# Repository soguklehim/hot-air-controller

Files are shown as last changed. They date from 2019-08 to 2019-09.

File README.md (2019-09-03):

# Hot Air Rework Controller for generic 858D / 85x heat guns

A small, portable and robust hot air controller for generic Chinese 858D / 8586 / 8858 / 852 / 878 / 858 hot air guns.

### Index
- [Schematics and BOM](/hardware)
- [Docs (guide for selecting and testing compatible hot air guns, assembly documents, manual)](/docs)
- Software (coming soon)

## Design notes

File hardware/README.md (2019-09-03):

### Table of contents

This project consists of two boards: Control and Power.

- Schematics: click on PDF files above
- BOM: click on XLSX files above
- Cutting files for SMD stencil: click on DXF files above

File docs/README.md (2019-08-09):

### Table of contents

- [User's manual](manual.md)
- [Guide for selecting and testing compatible hot air guns](hotairgun_guide.md)
- [PCB and assembly notes](pcb_assembly_notes.md)
- [A copy of the product description on Tindie, for version control](product_description.md)

You can get the boards or the complete controller on my store.



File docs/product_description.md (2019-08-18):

Hot Air Rework Controller for generic 858D / 85x heat guns

A small, portable and robust hot air controller for generic Chinese 858D / 8586 / 8858 / 852 / 878 / 858 hot air guns.

> Please note: Since Tindie does not allow shipping tiers based on product option, I need to select an option that can cover shipping of the assembled controller. Shipping blank boards cost less so I reduced its price to compensate that. I had to write this based on feedback received. Hope that's clear. Thank you.

## General Specifications and Features

-   Designed to use with Chinese 858D / 8586 / 8858 / 852 / 878 / 858 hot air guns.
-   Aims to be a safer alternative compared to existing controllers. For example:
    -   It will [not](https://www.youtube.com/watch?v=WPy9XYGDmWQ) [try](https://www.youtube.com/watch?v=WPy9XYGDmWQ) [to](https://www.youtube.com/watch?v=A319o8Ji4oI) [kill](https://www.youtube.com/watch?v=pgR7YbXUivs) [you](https://www.eevblog.com/forum/chat/deadly-wiring-fault-atten-858d-hot-air-rework-station/) (if you have a GFCI): Mains and earth connection are correctly wired.
    -   It will not [spontaneously combust](https://www.youtube.com/watch?v=tUFW5teeRBM) when left alone: Cuts off the hot air gun heater completely from mains after an idle timeout. Protects even if the unlikely event of TRIAC failure thanks to an internal relay.
    -   Safe to remove/change hot air gun while powered on: Both mains hot and neutral is disconnected from the front connector when the tool is removed so it is always safe to touch. 
-   Celsius or Fahrenheit display modes.
-   Works with the stand/holder: You can use the original holder or make your own with magnets.
-   Cools the tool down when in stand, with set thresholds.
-   Goes to sleep if left on stand. Selectable intervals or can be disabled. Wakes up automatically when needed.
-   Selectable power-on temperature and air: It can remember the last used settings as well (default).
-   Power limit: You can limit the maximum heating power on demand. Useful with under-powered UPSes or generators.
-   Selectable AC power regulation strategy: Phase angle (more precise) or pulse skip (less noisy).\* 
-   Internal temperature sensor used for compensating ambient temperature.
-   Manual calibration for ambient and tool set temperature.
-   Controller itself will work with 100-250V AC, 30-80Hz. (but you MUST use a hot air gun that rated for your mains voltage)

## Video
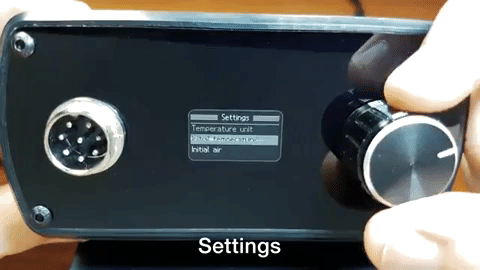
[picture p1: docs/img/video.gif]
Hot Air Rework Controller (https://youtu.be/jJAIh5CGPLk)


## Important!

This product is only a controller for specified hot air guns. **You must also have the hot air gun itself and its stand for a working system. These are not included.** These hot air guns are cheap and may arrive defective from manufacturing or shipping. Defective/incompatible hot air guns may damage the controller and/or trip your GFCI or worse. **It is entirely your responsibility to check if the hot air gun is compatible and not defective (use my guide for this). I cannot be held responsible if anything bad happens to controller or you. This is a DIY product. It does not have any certifications. I hope you have been sufficiently warned.**

[Click here for the hot air gun guide](https://github.com/soguklehim/hot-air-controller/blob/master/docs/hotairgun_guide.md)

## Options

You have three options that you can choose based on how adventurous are you.

1.  **Fully assembled controller**
    
    -   Includes one Hot Air Controller, tested and ready to work.
	
2.  **Assembled boards**
    
    -   Includes one front panel assembly (Control board + front panel) and one Power board, with all components mounted and tested.
    -   This is equals to Option 1 minus the case, back panel and AC socket. Mount it to a case of your liking, wire Power board to AC mains connection and it is ready to work.
	
3.  **Empty boards**
    
    -   Includes one blank Control board and one blank Power board. Without components, **but an unsoldered, preprogrammed ATMEGA328P-AU will be included** for the controller board. Use the provided BOM and your DIY skills for a working controller.

## You'll also need (not included)

-   AC power cable 
-   Hot air gun
-   Hot air gun stand

## Open(-ish) source

**Following elements of this product are available free of charge:**

-   Control and power board schematics
-   Control and power board BOM and assembly guide
-   Open source version of source code (coming soon)
    -   If you purchase an option that includes an assembled control board, it'll sent preprogrammed with the "closed" version of the code. Open source version has different fonts and temperature control algorithm (because I can't redistribute the sources of these). Otherwise, functionality is the same. 

> Originally this is going to be closed source (like all of my hardware products) but I decided to release an open version of the work due to popular demand. Porting things to Arduino ecosystem and replacing/rewriting/converting closed source to open takes time. It is still ongoing and I'm currently investing my time on that but it is not my first priority. Thank you for your understanding.

All assembled control boards ships with unlocked Optiboot bootloader. ICSP pins are also broken out if you really need that 0.5K. Happy hacking!

[Link to the repo](https://github.com/soguklehim/hot-air-controller/)

## Physical:

-  Dimensions: 110x105x50mm
-  Weight: 400gr

## Notes:

-   Currently shipping:
	-   Firmware: v1.0.24
    -   Control board: v1.0
    -   Power board: v1.1
-   AC input socket: IEC 60320 C14: Also known as "computer cable". (for assembled option)
-   Please read the "Shipping Policies" section at the store page ("View Store" button) before ordering.

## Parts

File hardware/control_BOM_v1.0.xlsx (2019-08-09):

Parts | Qty | Value | Description
C1, C2, C8, C9 | 4 | 10n | Multilayer Ceramic Capacitors MLCC - SMD/SMT 10nF 100V 0805 RoHS
C11 | 1 | 1u | Multilayer Ceramic Capacitors MLCC - SMD/SMT 1uF 50V 0805 RoHS
C13 | 1 | 220u 10V | Aluminum Electrolytic Capacitors - SMD 220uF ±20% 16V SMD,6.3x7.7mm RoHS
C3, C6, C10, C12, C14 | 5 | 100n | Multilayer Ceramic Capacitors MLCC - SMD/SMT 100nF 50V 0805 RoHS
C4, C5 | 2 | 22p | Multilayer Ceramic Capacitors MLCC - SMD/SMT 22pF 50V 0805 RoHS
C7 | 1 | 100u 35V | Aluminum Electrolytic Capacitors - SMD 100uF ±20% 35V SMD,6.3x7.7mm RoHS
D1 | 1 | SM4007PL | Diodes - General Purpose 1kV 1A 1.1V @ 1A SOD-123FL RoHS
D2 | 1 | BAV199 | Diodes - General Purpose 85V 160mA 1.25V @ 150mA SOT-23(SOT-23-3) RoHS
F1 | 1 | PTC 750mA | PTC Resettable Fuses 1206 RoHS
IC1 | 1 | GS8591 | Precision OpAmps SOT-23-5 RoHS
IC3 | 1 | 78M05 | Linear Voltage Regulators TO-252-2(DPAK) RoHS
LED1 | 1 | Green | Light Emitting Diodes (LED) Green 525~530nm 500~1080mcd@20mA Top View 1206 RoHS
NTC | 1 | 10k | NTC Thermistors 10KOhms ±5% 3950K 0805 RoHS
Q1 | 1 | AO3406 / CJ2306 | MOSFET N Trench 30V 3.16A 3V @ 250uA 47 mΩ @ 3.5A,10V SOT-23(SOT-23-3) RoHS
R1, R2, R8, R9, R11, R16, R17 | 7 | 10k | Chip Resistor - Surface Mount 10KOhms ±1% 1/8W 0805 RoHS
R12, R13 | 2 | 4k7 | Chip Resistor - Surface Mount 4.7KOhms ±1% 1/8W 0805 RoHS
R15 | 1 | 3k | Chip Resistor - Surface Mount 3KOhms ±1% 1/8W 0805 RoHS
R18 | 1 | 330 | Chip Resistor - Surface Mount 330Ohms ±1% 1/8W 0805 RoHS
R19 | 1 | 15k | Chip Resistor - Surface Mount 15KOhms ±1% 1/8W 0805 RoHS
R3 | 1 | 1M | Chip Resistor - Surface Mount 1MOhms ±1% 1/8W 0805 RoHS
R4 | 1 | 100k | Chip Resistor - Surface Mount 100KOhms ±1% 1/8W 0805 RoHS
R5, R14, R20 | 3 | 470k | Chip Resistor - Surface Mount 470KOhms ±1% 1/8W 0805 RoHS
R6 | 1 | 150 | Chip Resistor - Surface Mount 150Ohms ±1% 1/8W 0805 RoHS
R7, R10 | 2 | 1k | Chip Resistor - Surface Mount 1KOhms ±1% 1/8W 0805 RoHS
U1 | 1 | ATMEGA328P-AU | ATMEL & AVR TQFP-32_7x7x08P RoHS
X2 | 1 | JST-XH-05 | Wire To Board / Wire To Wire Connector Plugin RoHS
Y1 | 1 | 16MHz | SMD Crystal Resonators 16MHz ±20ppm HC-49SMD RoHS
-no designator- | 1 | 33uF 35V | to be soldered on hot air connector pins 5 and 6

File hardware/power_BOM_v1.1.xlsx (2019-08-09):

Parts | Qty | Value | Description
CX1 | 1 | 10n | Suppression Capacitors 10nF ±10% Through Hole,P=10mm RoHS
D1 | 1 | SM4007PL | Diodes - General Purpose 1kV 1A 1.1V @ 1A SOD-123FL RoHS
D2 | 1 | P6KE440CA | TVS DO-15 RoHS
HS1 | 1 | HEATSINK | Heat Sinks 32*7*22 RoHS
K1 | 1 | HCP2-DC24V-C | Relays General Purpose Non Latching 24VDC DPDT 8A (440VAC , 120VDC) Max Plugin RoHS
M1 | 1 | GMY-001F | https://www.aliexpress.com/item/AC-100-265V-to-DC-24V-1A-Switching-Power-Supply-Module-Board-For-Replace-Repair/32862962719.html
OK1 | 1 | PC814 | DIP Optocouplers SMD-4 RoHS
OK2 | 1 | MOC3053S | Triac Optocouplers SMD-6 RoHS
Q1 | 1 | AO3406 | MOSFET N Trench 30V 3.16A 3V @ 250uA 47 mΩ @ 3.5A,10V SOT-23(SOT-23-3) RoHS
R1, R2, R3, R4 | 4 | 39k | Chip Resistor - Surface Mount 39KOhms ±5% 1/2W 2010 RoHS
R10 | 1 | 39 | Metal Film Resistor (TH) 39Ohms ±1% 1W Axial RoHS
R11 | 1 | 10D431K | Varistors 350V 430(387~473) 710V 2.5KA Through Hole RoHS
R5 | 1 | 1k | Chip Resistor - Surface Mount 1KOhms ±1% 1/8W 0805 RoHS
R6 | 1 | 10k | Chip Resistor - Surface Mount 10KOhms ±1% 1/8W 0805 RoHS
R7 | 1 | 330 | Chip Resistor - Surface Mount 330Ohms ±1% 1/8W 0805 RoHS
R8 | 1 | 360 | Chip Resistor - Surface Mount 360Ohms ±5% 3/4W 2010 RoHS
R9 | 1 | 330 | Chip Resistor - Surface Mount 330Ohms ±5% 3/4W 2010 RoHS
T1 | 1 | BTA16 | Thyristors - TRIACs Two-way thyristor 600V TO-220(TO-220-3) RoHS
X1 | 1 | JST-XH-02-PIN | Wire To Board / Wire To Wire Connector Plugin RoHS
X2 | 1 | JST-XH-03-PIN | Wire To Board / Wire To Wire Connector DIP RoHS
X3 | 1 | 7.62mm Screw Terminal | Barrier Terminal Blocks 7.62mm RoHS OR Blade Terminals
X4 | 1 | JST-XH-05-PIN | Wire To Board / Wire To Wire Connector Plugin RoHS
X5 | 1 | B3P-VH | Wire To Board / Wire To Wire Connector P=3.96mm RoHS
- | 4 | PCB nylon standoff | 3mm hole size 5mm height self retaining spacers

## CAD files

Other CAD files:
hardware/power-bcream.dxf
hardware/control-bcream.dxf

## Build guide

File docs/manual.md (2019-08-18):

# User's Manual
##### For v1.0.24 SW

## Table of contents
- [Getting started](#getting-started)
- [How to use](#how-to-use)
- [Settings menu](#settings-menu)
- [Troubleshooting](#troubleshooting)
- [Calibration](#calibration)

---

## Getting started
This document assumes that you have:
- An assembled Controller from us OR made your DIY version and fully tested beforehand,
- Followed the [hot air gun guide](hotairgun_guide.md) and have a suitable hot air gun and a stand at hand,
- Installed the correct fuse for your country (220V: 4A, 110V: 8A) to the Controller,
- Connected the Controller to a GFCI protected outlet.

The Controller itself can work with 100-250V AC, 30-80Hz and requires a clean AC line, like all TRIAC based devices. **Using it with generators or especially modified sine / square wave / line-interactive / cheap UPSes is not recommended.** True sine wave / online UPSes over 1KVa should work fine. In fact, the Controller designed to tolerate dirty networks and more forgiving than most appliances but reliable operation is not guaranteed if anything other than your standard AC line is being used.

---

## How to use
You control everything with the knob. Rotating right (clockwise) means increase; rotating left (counterclockwise) is decrease. Short press (click) will change between temperature and air in the main screen, it means select/OK on settings. A long press will take you to the settings, or takes you back to the main screen if you're already in a menu.

This is the main screen.

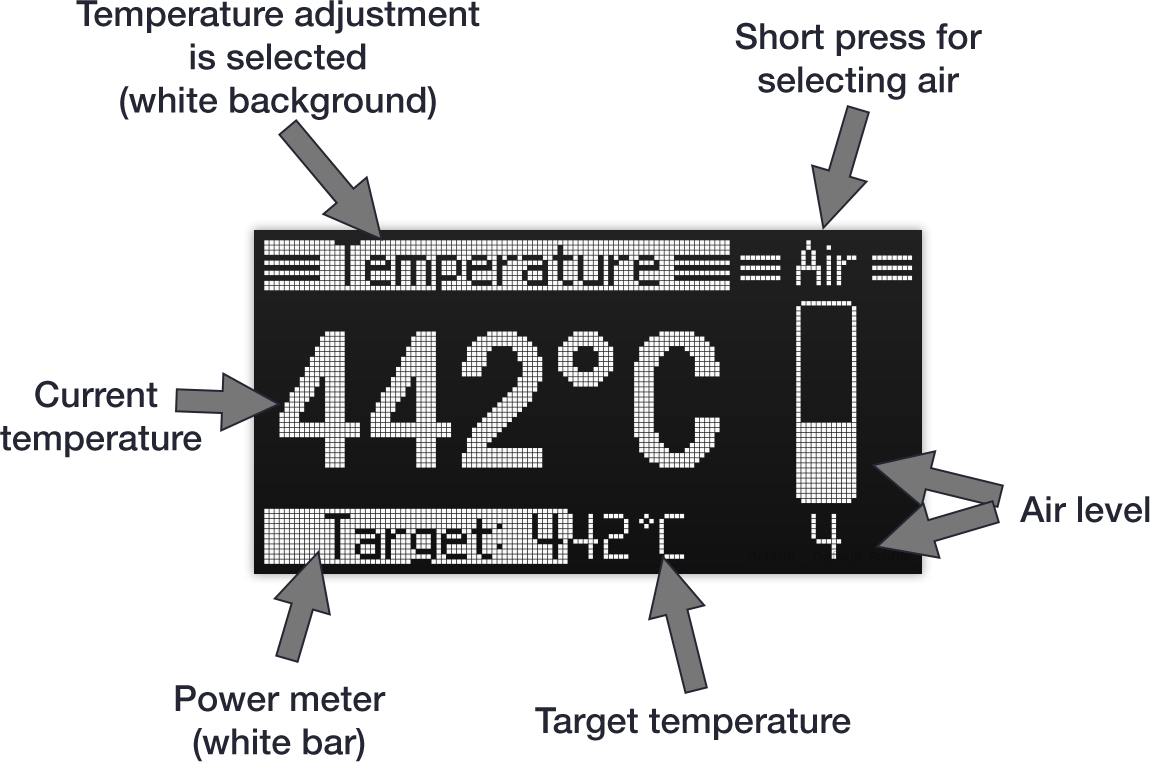
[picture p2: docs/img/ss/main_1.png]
main_1


You can choose to adjust temperature and air. Currently temperature is selected, so if you rotate the knob the set (target) temperature will change. 

While you're changing the temperature, the set value moves to the top for a short period so you can see and adjust it easier. In that short period, the current temperature can be seen at bottom.

For changing the selection, "click" (shortly press) the knob.

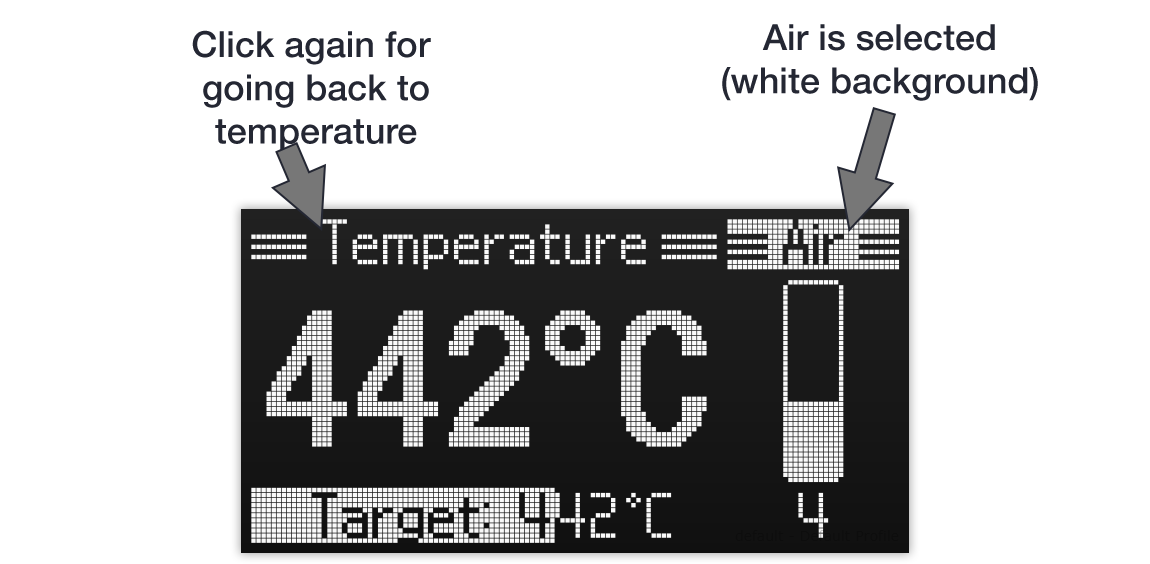
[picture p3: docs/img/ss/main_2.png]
main_2


Now the air is selected. You can change the air setting by rotating the knob.

If you put the tool on stand, Controller switches to Standby mode. It'll start to cool the nozzle using with maximum air speed. Fan will stop when it is cooled down. When you pick it from the stand, it immediately starts heating using the last temperature and air values.

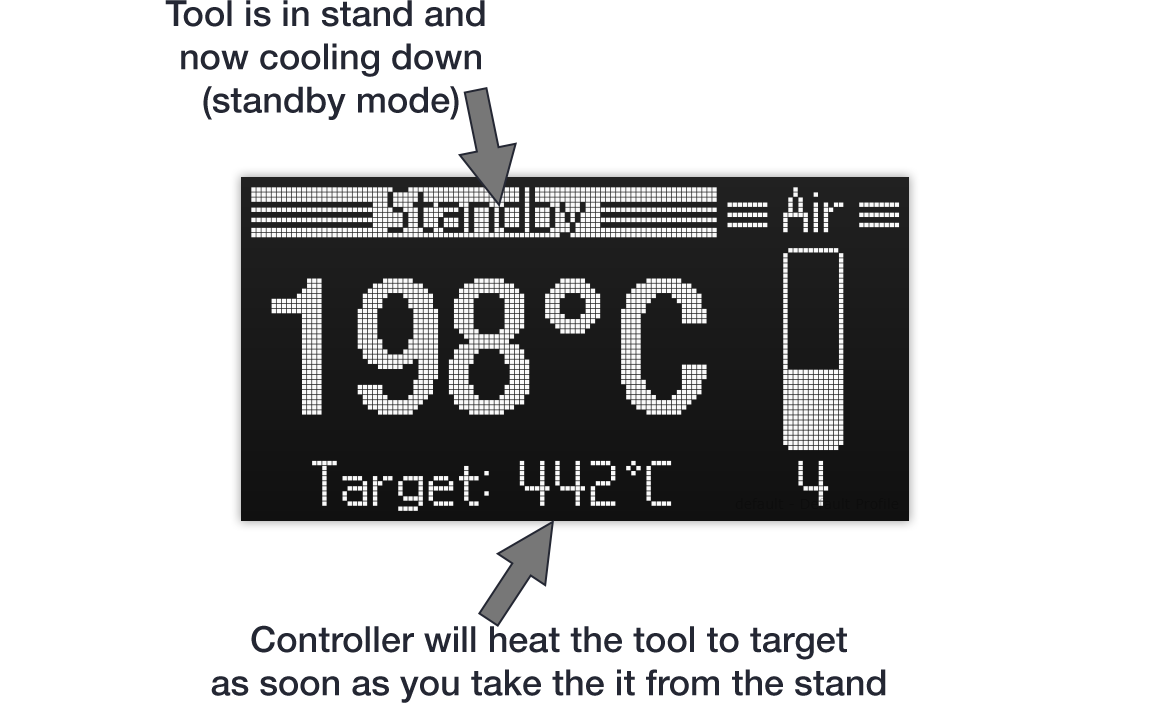
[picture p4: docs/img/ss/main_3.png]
main_3


That's it. Happy reworking!

---

## Settings menu

A long press to the knob will take you to the settings. It takes you back to the main screen if you're already in a menu. Use the long press for exit without saving. Click (short press) for choosing the selected option.

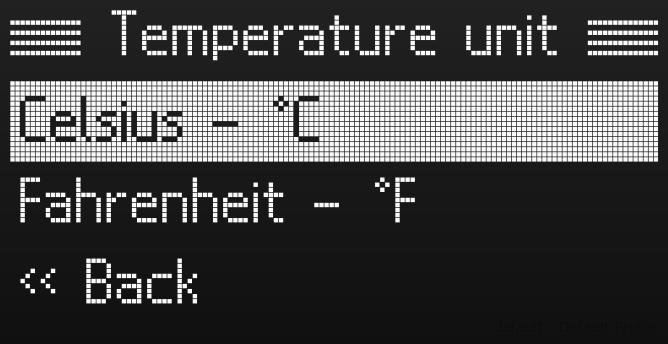
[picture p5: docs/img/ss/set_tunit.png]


**Temperature unit** 

You can select your temperature unit of your choice between Celsius or Fahrenheit.
<br clear="both"/>

------

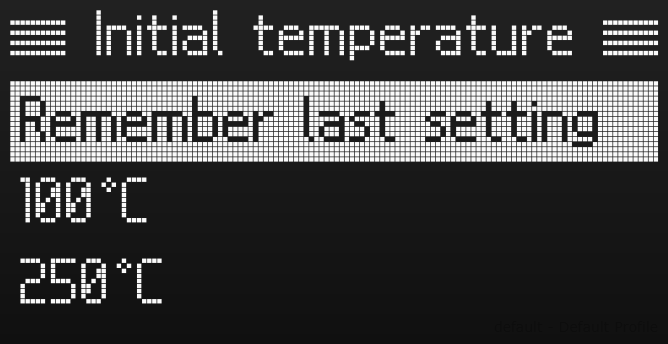
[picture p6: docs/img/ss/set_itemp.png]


**Initial temperature** 

You can select the temperature when the Controller boots up. It'll remember the last setting by default.
<br clear="both"/>

------

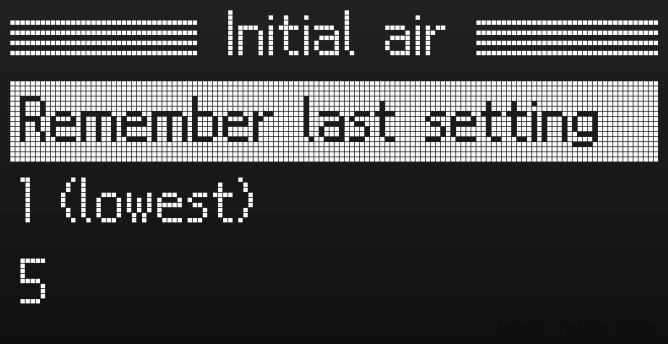
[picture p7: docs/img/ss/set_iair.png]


**Initial air**

You can select the air when the Controller boots up. It'll remember the last setting by default.
<br clear="both"/>

------

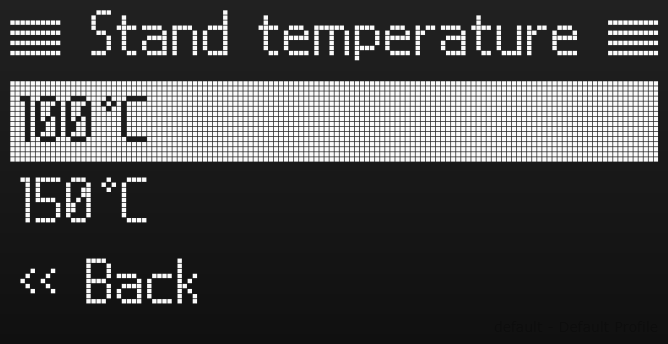
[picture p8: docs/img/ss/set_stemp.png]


**Stand temperature** 

Controller will cool the tool when it is in the stand for safety purposes. You can set that cooldown threshold here.
<br clear="both"/>

------

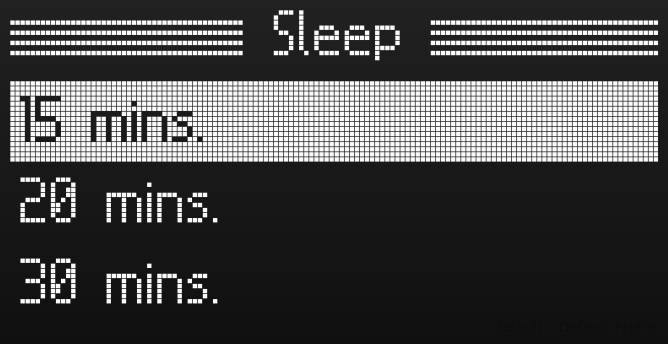
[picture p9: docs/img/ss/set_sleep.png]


**Sleep** 

Controller will enter to sleep mode if the tool stays in the stand for a while. You can select that timeout here. It will wake up when you take the tool from the stand, remove the tool or touch the encoder. 
<br clear="both"/>

------

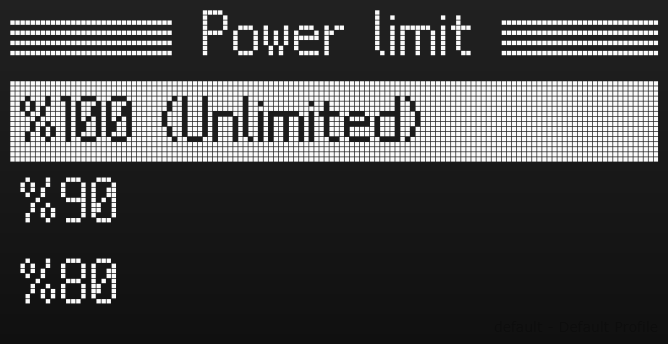
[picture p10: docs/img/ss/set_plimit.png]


**Power limit** 

Controller can limit the power that it'll deliver to the tool. This will reduce the heating performance so it is recommended to keep it at full power for daily usage. If you have to use your Controller with an underpowered generator or UPS, this will help you.
<br clear="both"/>

------

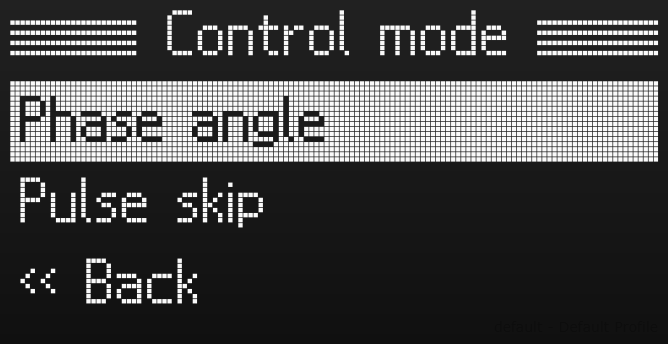
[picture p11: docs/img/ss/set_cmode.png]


**Control mode** 

This is an advanced setting for choosing how the power is delivered to the heater. In contrast of phase angle control, the pulse skip mode will deliver full half waves to the heater without chopping, thus minimizing the noise. Do not use pulse skip on small UPSes or generators, this setting makes them unhappy. Phase angle is the default setting.
<br clear="both"/>

------

**About** 

Gives the firmware version, language and operation time. Long press to exit.

------

**Exit** 

Returns you to the main screen.

---

## Troubleshooting

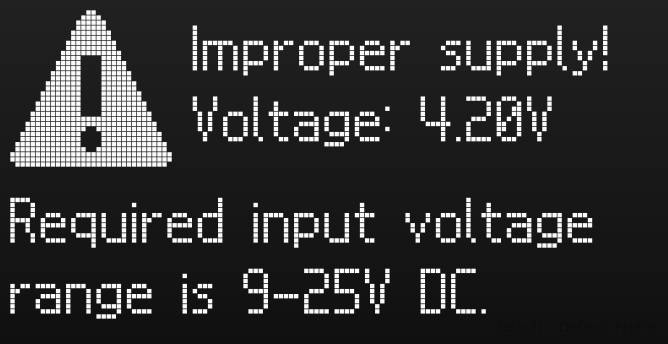
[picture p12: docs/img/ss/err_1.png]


**Improper supply error** 

This is related to internal SMPS that powers the Controller and the tool fan. Controller will refuse to work when its supply is out of the range. Power cycle the unit, if the error clears itself you'll most likely encountered a power glitch comes from your national grid. 

If the error keeps reappearing, you should measure the output voltage from the internal SMPS. If the readings are also out of the range, change the SMPS. If the readings are OK, check the voltage divider resistors on Controller PCB.
<br clear="both"/>

------

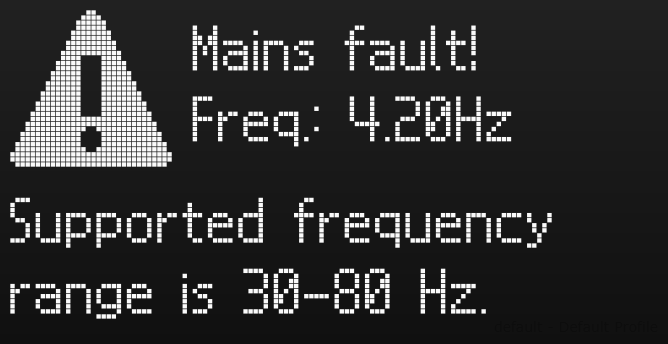
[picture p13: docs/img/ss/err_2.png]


**Mains fault** 

Controller needs to precisely follow the mains frequency for controlling the heater. If the mains frequency out of limits for a while, it'll shut off and gives this error. Since the Controller supports wide frequency range, this error is fairly rare and generally related with a power outage. If your AC power blips you may get this error. Power cycle the unit and it'll clear out. 

If you're trying to use the Controller with a "synthetic" supply (a generator or UPS) and you keep getting this error, it generally means your supply generating extreme amount of noise or instead producing a sinewave it outputs ＶＡＰＯＲＷＡＶＥ or something. Jokes aside, it means the Controller cannot work with this supply. Please use a normal AC outlet.
<br clear="both"/>

---

## Calibration

**Note:** If you have got an assembled Controller from us, it is already calibrated. **Calibration menu do not have the usual safeguards and it won't prevent you messing something up. Proceed with caution.** It is suggested to take a note of current settings before changing anything.

If you DIY your controller, the calibration menu will automatically pop up on the first power on. You can skip the this by long pressing, but it'll keep asking until you do (and tell the controller as such).

For entering the calibration menu, go to Settings > About and click the knob 10 times. Here is what you get:

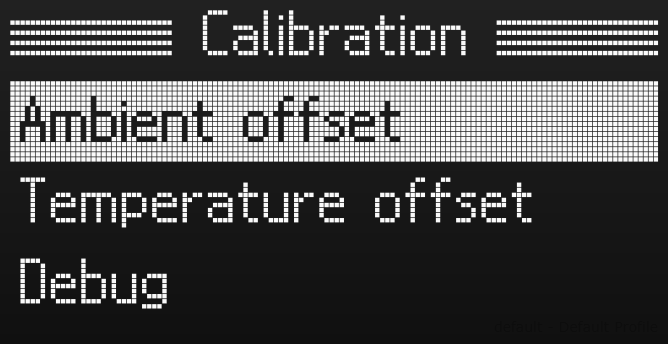
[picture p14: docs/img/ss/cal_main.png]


There is two different offsets available for calibration: ambient and temperature. Ambient will trim the internal NTC, temperature is for the thermocouple in the tool. **Both settings will have an effect on the final temperature reading.**

**Start the calibration with a cold (room temp.) controller for the best accuracy. Set air to the max. Switch controller to Celsius. Use the phase angle control mode.** You'll need a external temperature measurement device to calibrate against, so by definition it should be good enough. Your calibration device of choice should measure 300°C.

Calibration screens are pretty self-explanatory. Start with the ambient offset. Adjust it so the *Val* represents the actual ambient temperature. Click for save the offset. 

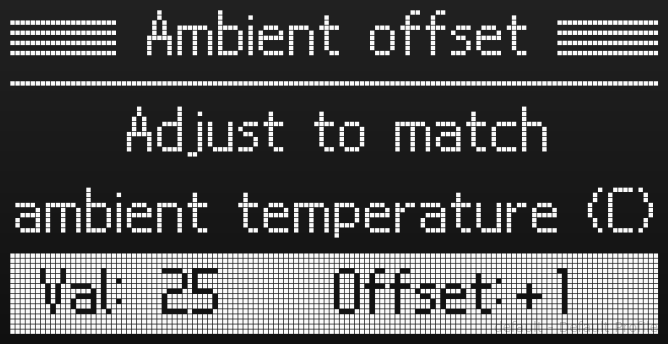
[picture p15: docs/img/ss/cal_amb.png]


Proceed to temperature offset. On this step you'll need the tool plugged in. It'll heat it to 300°C. You should measure the nozzle output air temperature and add/remove an offset so *Val* matches the value that you externally read.

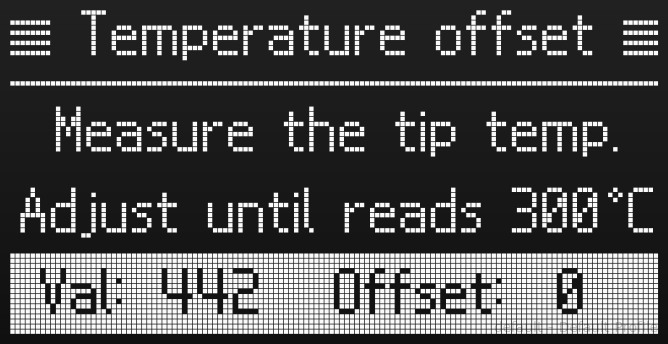
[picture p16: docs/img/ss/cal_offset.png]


Reliably measuring airflow temperature is not that easy as you may assume. I suggest using a small nozzle attachment and by using a third hand position your probe directly front of the nozzle but not touching the metal. Give the heater ~1min of time to settle and start adjusting the offset. Once you're satisfied, click to save.

Use the "Mark as calibrated" menu item after the calibration if this is the first time.

**Debug: ** If you are "real men use raw ADC values" type of person, this is for you. It replaces the main screen with bunch of values until the next power cycle.

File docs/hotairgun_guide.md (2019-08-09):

## Hot air gun guide

**Keywords for finding a compatible hot air gun:** "858 hot air gun 8 holes"

**Keywords to avoid:** 898, Yihua 898BD (looks exactly the same but incompatible)

It should look like this: 
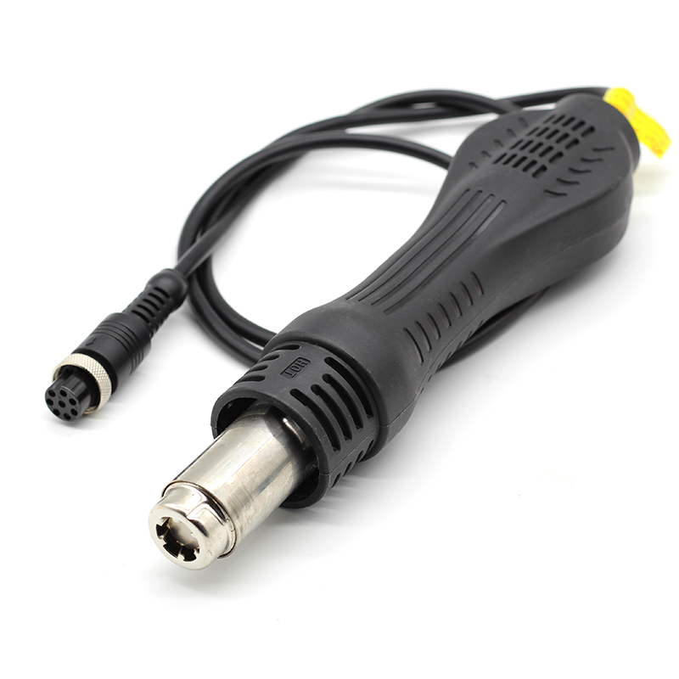
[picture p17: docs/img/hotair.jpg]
Hot Air Gun


**Connector:** GX16-8

**Pinout [Cable Color]:** 
1. TC + [Orange]
2. TC-, Reed [White]
3. Reed [Yellow]
4. PE [Green]
5. Fan - [Blue]
6. Fan + (24V) [Brown]
7. Heater (AC!) [Red]
8. Heater (AC!) [Black]

**Cable colors only for reference. There is no standards in China - always measure to be sure.**

### Checklist: 

 1. **Visual check:** Check for any anomalies, cracks, dents etc. Check the tip of the air gun, it should look protruded like in the photo. If it is looks like depressed in, it is damaged in shipping. This portion, when sunked in, may directly contact to the heater core itself and create a short. Get a refund, or only use it after a complete disassembly and extensive inspection.
 2. **Heater coil (pins 7-8):** Measure resistance pins between 7 and 8, it should be 60-80ohm for 220V guns and 15-30ohm for 110V guns.
	*  Do not proceed if your reading doesn't match the reference above.
	* Check for continuity 7 and 8 between all other pins. Do not proceed if you measure any resistance.
2. **PE (pin 4):** Verify continuity between this pin and the metal gun tip. 
	* Do not proceed if you measure a resistance higher than 1 ohms.
3. **Reed relay (pins 2-3):** Verify that you measure between pins 2-3 
	* Continuity (<1 ohms), when the air gun is in the stand
	* Open line (infinite ohms), when the air gun is not in the stand
4. **Fan test (optional):** Supply 12-24V DC to pins 5 (-) and 6 (+). You should hear and feel the fan is running.
5. **Thermocouple test (optional):** There is a K type thermocouple in the air gun that is connected to pins 1 and 2. If your multimeter has a range for temperature measurement use this. If not, use the DC millivolt range. With a lighter heat the metal section of the air gun for 10 seconds. You should read a temperature/voltage increase. If the measured temperature/voltage decreases check your connection, you may connected the TC lines reversed. If there is no change after 10 seconds of heating, do not proceed.

**Only connect the hot air gun to the controller after you run through the checklist. It is highly recommended that you inspect the internals of your air gun.**

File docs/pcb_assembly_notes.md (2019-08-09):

## PCB notes

You can use the provided DXF files for making a SMD stencil if you have access to a laser cutter. Grab it from the `hardware` folder. It is adjusted for laser cutting, no extra pad swell required.

### v1.0 Control board render for assembly
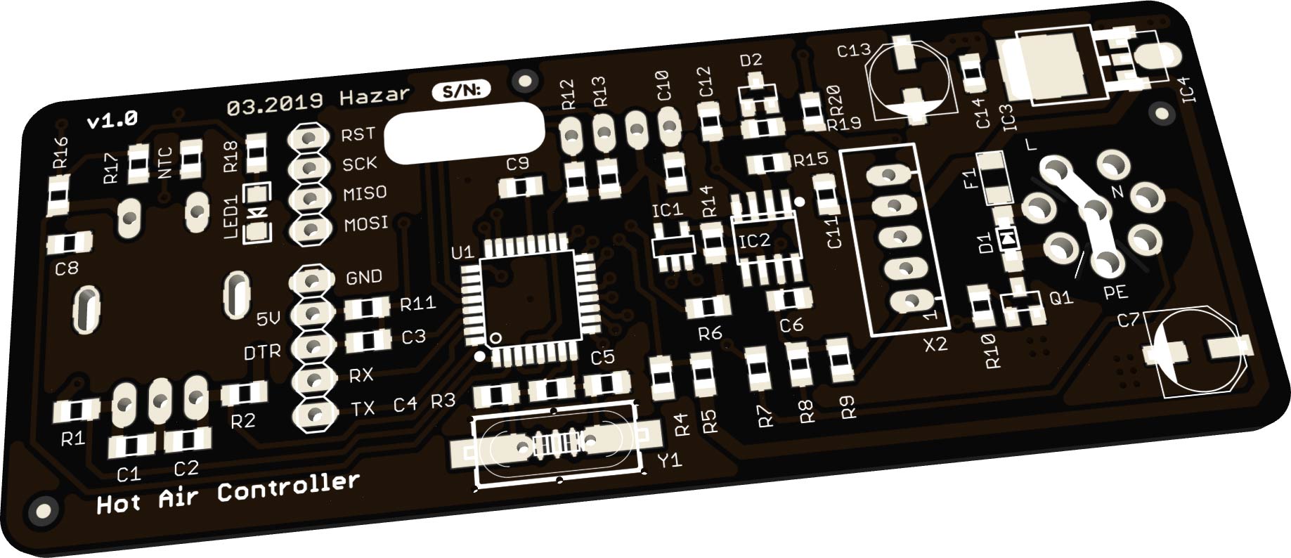
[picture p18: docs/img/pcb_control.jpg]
Control Board


### v1.1 Power board render for assembly
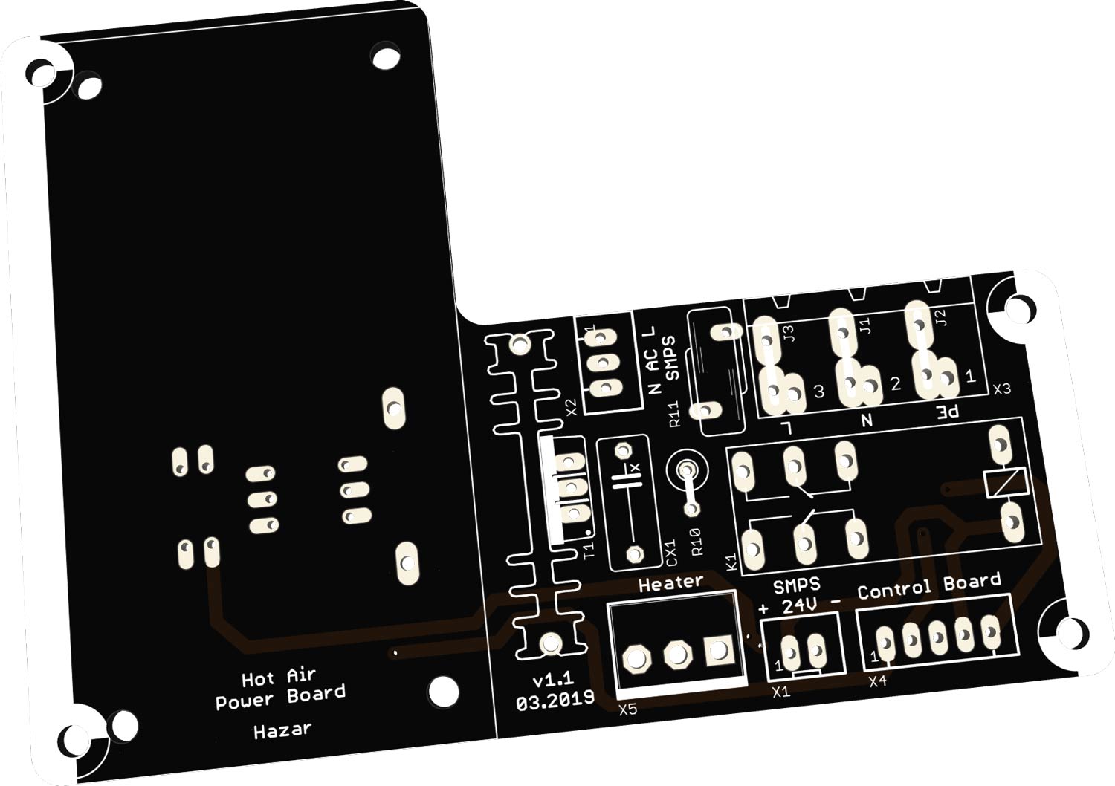
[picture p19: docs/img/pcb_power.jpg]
Power Board


Actual hardware uses green PCBs.

### PCB Errata

Please read if you purchased bare PCBs. Assembled unit owners don't affected - required action already taken by us while assembling.

 - v1.1 Power PCB's has three silkscreen errors:
	- AC input terminals swapped L with N. **This is amended by applying a sticker covering over the top silkscreen. No boards shipped without a sticker. Every order that includes a bare board ships with a reminder about that. Every assembled unit is wired correctly.** Sorry about that. Board renders above has the corrected silkscreen.
    - OK1's orientation marker **dot** is wrong but the **line** is correct. Align the dot on the component itself with the line on the board. 
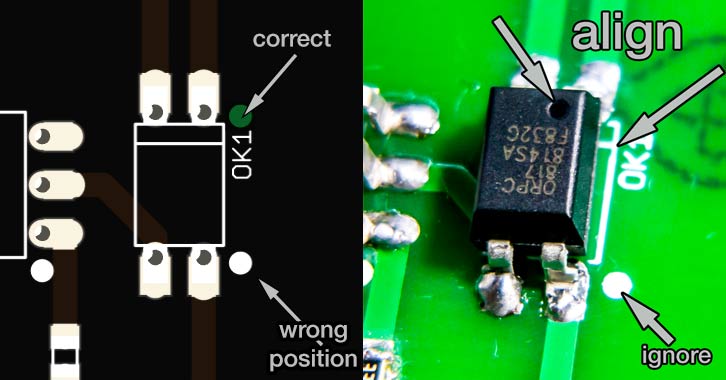
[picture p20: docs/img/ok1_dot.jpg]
Dot Dot.
	
    - D2 is a bidirectional TVS. Ignore the cathode marking on the board silkscreen, it can be mounted either direction. 

## Assembly notes

### Control board:

 - IC1/IC2 (opamp) and IC3/IC4 (voltage regulator) are alternative footprints on PCB. Only one of them meant to be populated in each pair. BOM components uses IC1 and IC3 (leaves IC2 and IC4 empty). If you prefer to use a different voltage regulator or opamp, you have two different footprint options.
 - For crystal Y1, 3 different footprints provided in the same package. HC-49, HC-49S (crystal) and ceramic resonator. Most ceramic resonators include built-in load capacitors, in that case do not mount C4 and C5. 
 - Solder a 30-60μF 35V capacitor to connector pins 5 (negative) and 6 (positive). In the next hardware version this is moved to the PCB.
 - Control board is isolated from AC mains. Only connector pins 7 and 8 itself wired to AC.

### Power board:
 - OK1 and OK2 should be mounted on the bottom side of the board. SMD and through-hole footprints are provided.
 - Trim all the through hole legs after soldering.
 - Power board AC mains connection also can be used with 3 male blade terminals. I use blade terminals on assembled controllers, BOM includes a screw terminal. 
 - Mount the SMPS to the Power board with 4 self retaining nylon spacers. Position SMPS AC input towards inside of the Power board.
 - This board carries AC mains. **Never** touch it when powered on.

### Cabling:
 - On the Power board, X2 (3 pin, middle pin unused) is the AC supply **to** the SMPS board. X1 (2 pin) is the DC output **from** SMPS board. Both SMPS and the Power board connections uses JST-XH connectors. These are keyed connectors so you can't easily in plug it wrong way. If you are assembling a blank board, take care of the polarity!
 - **Power to Control board - Heater power connection:**
	 - Thanks to the design choice made by hot air gun designers, it is **impossible** to route 700W carrying AC heater lines on the PCB without posing a fire hazard. 
	 - For this reason, GX16-8 connector has 3 pins that needs to be connected to the power board separately. These connections marked clearly as L, N and PE on the Control PCB. Solder 3 wires to these pins with heatshrink and terminate with a female VH connector. Then connect it to X5 on Power board, marked Heater. 
	 - X5 pinout: Pin 1 is PE, pin 2 is N, pin 3 is L. Looking at the bottom side, square pad is pin 1.
 - **Power to Control board - Control connection:**
	 - This connector marked X4 on Power board, X2 on Control board and uses 5 pin JST-XH connectors. 
	 - Connections on both boards uses same pin numbers. For example Pin 1 on Power board should connect to Pin 1 on the Control board. 
	 - If you are going to use premade JST-XH cables, just be sure that you're using the OPPOSITE connector direction variant. Same direction cables will REVERSE the pin order on the other end. 
		 - Making this mistake will damage the Control board quite spectacularly. Be careful.
 - **Power board to mains:**
	 - Since Power board itself is not fused, It is **mandatory** to use a fused socket. Fused and switched IEC 60320 C14 sockets are recommended. For 220V use 4A, for 110V use 8A fuse. 

### Notes
 - Correct PE connection and GFCI in your outlet/fuse box is only thing that will protect you from an electrocution risk on mains powered circuits. PE is your life insurance and it is important. If you use a metal enclosure/front panel etc., connect it to PE. If, for some reason you blow a fuse or trigger a GFCI **do not EVER try to power it again without finding and fixing the root cause.**

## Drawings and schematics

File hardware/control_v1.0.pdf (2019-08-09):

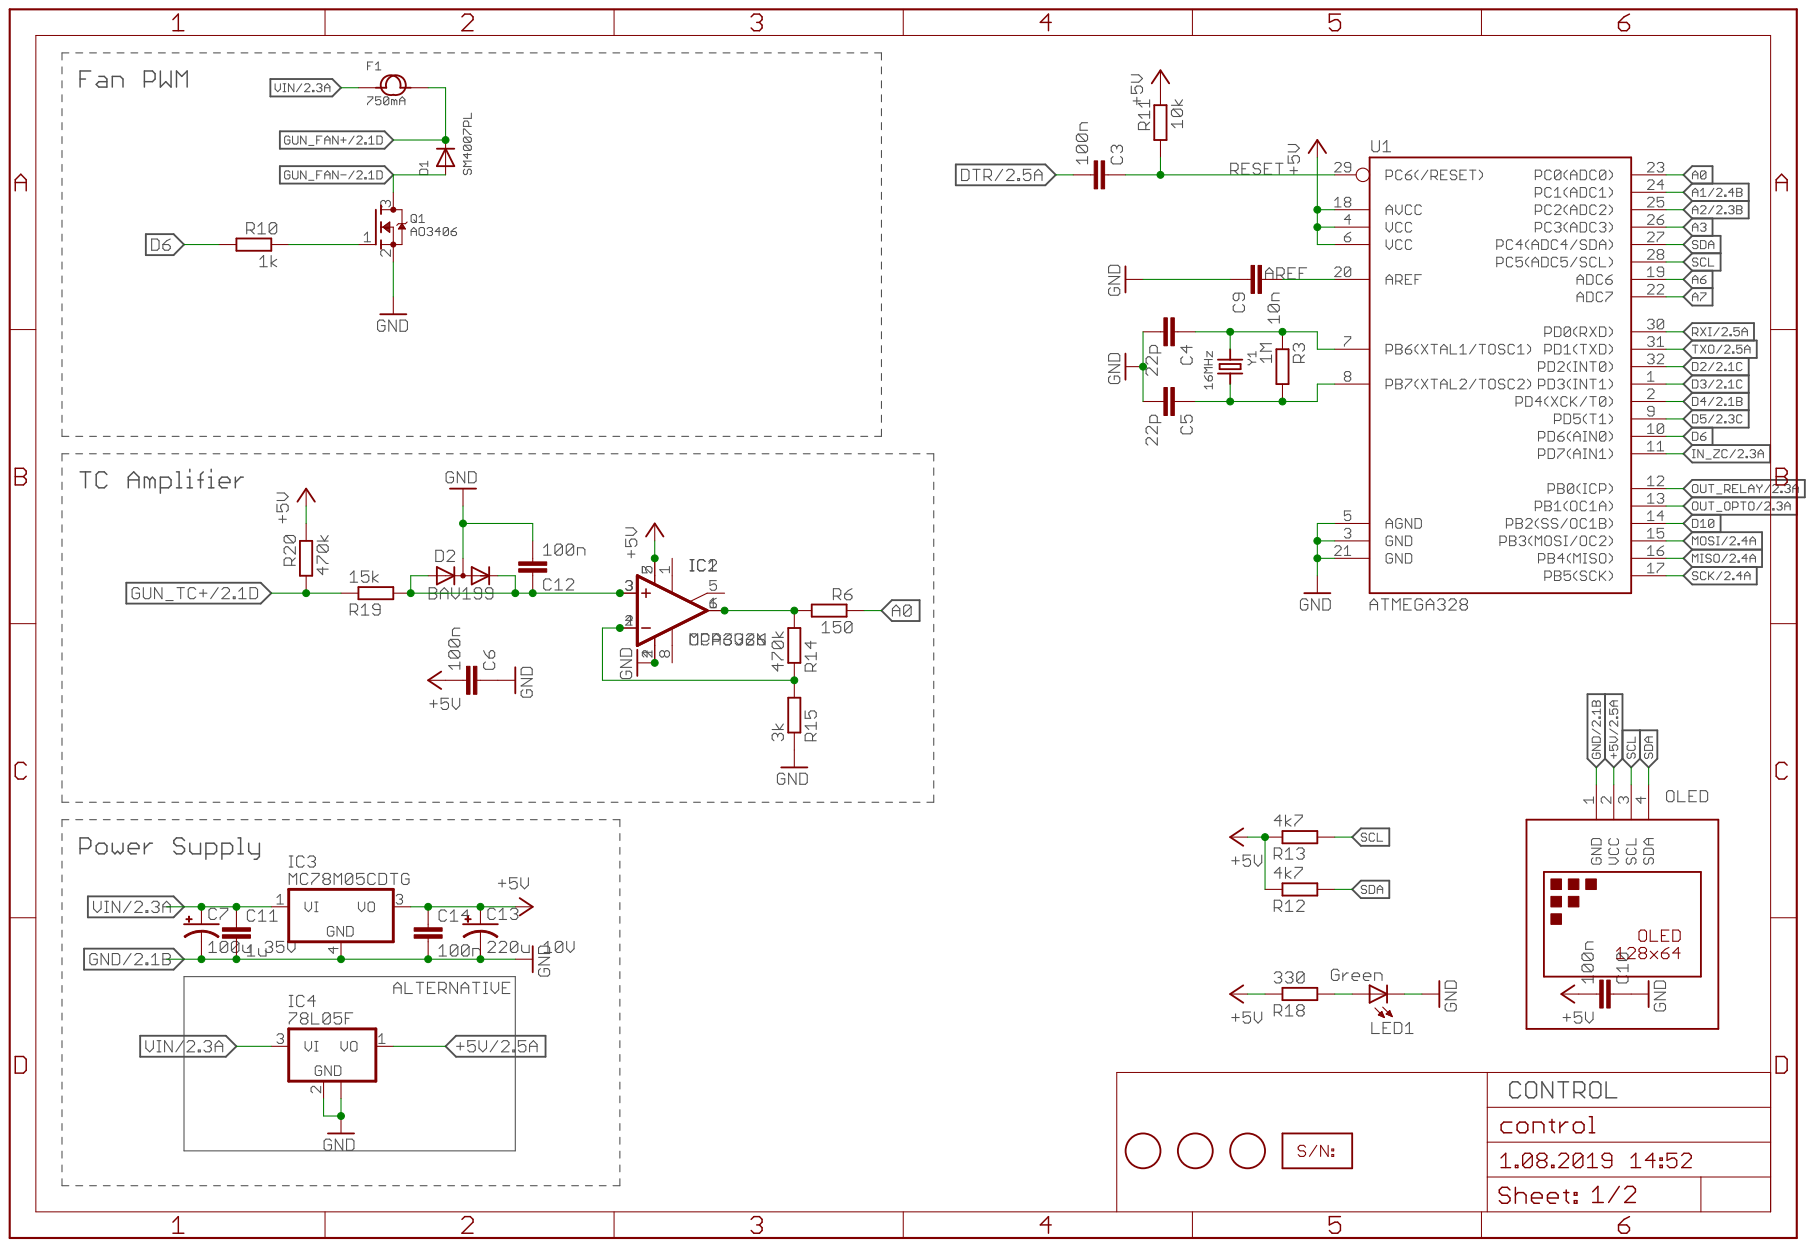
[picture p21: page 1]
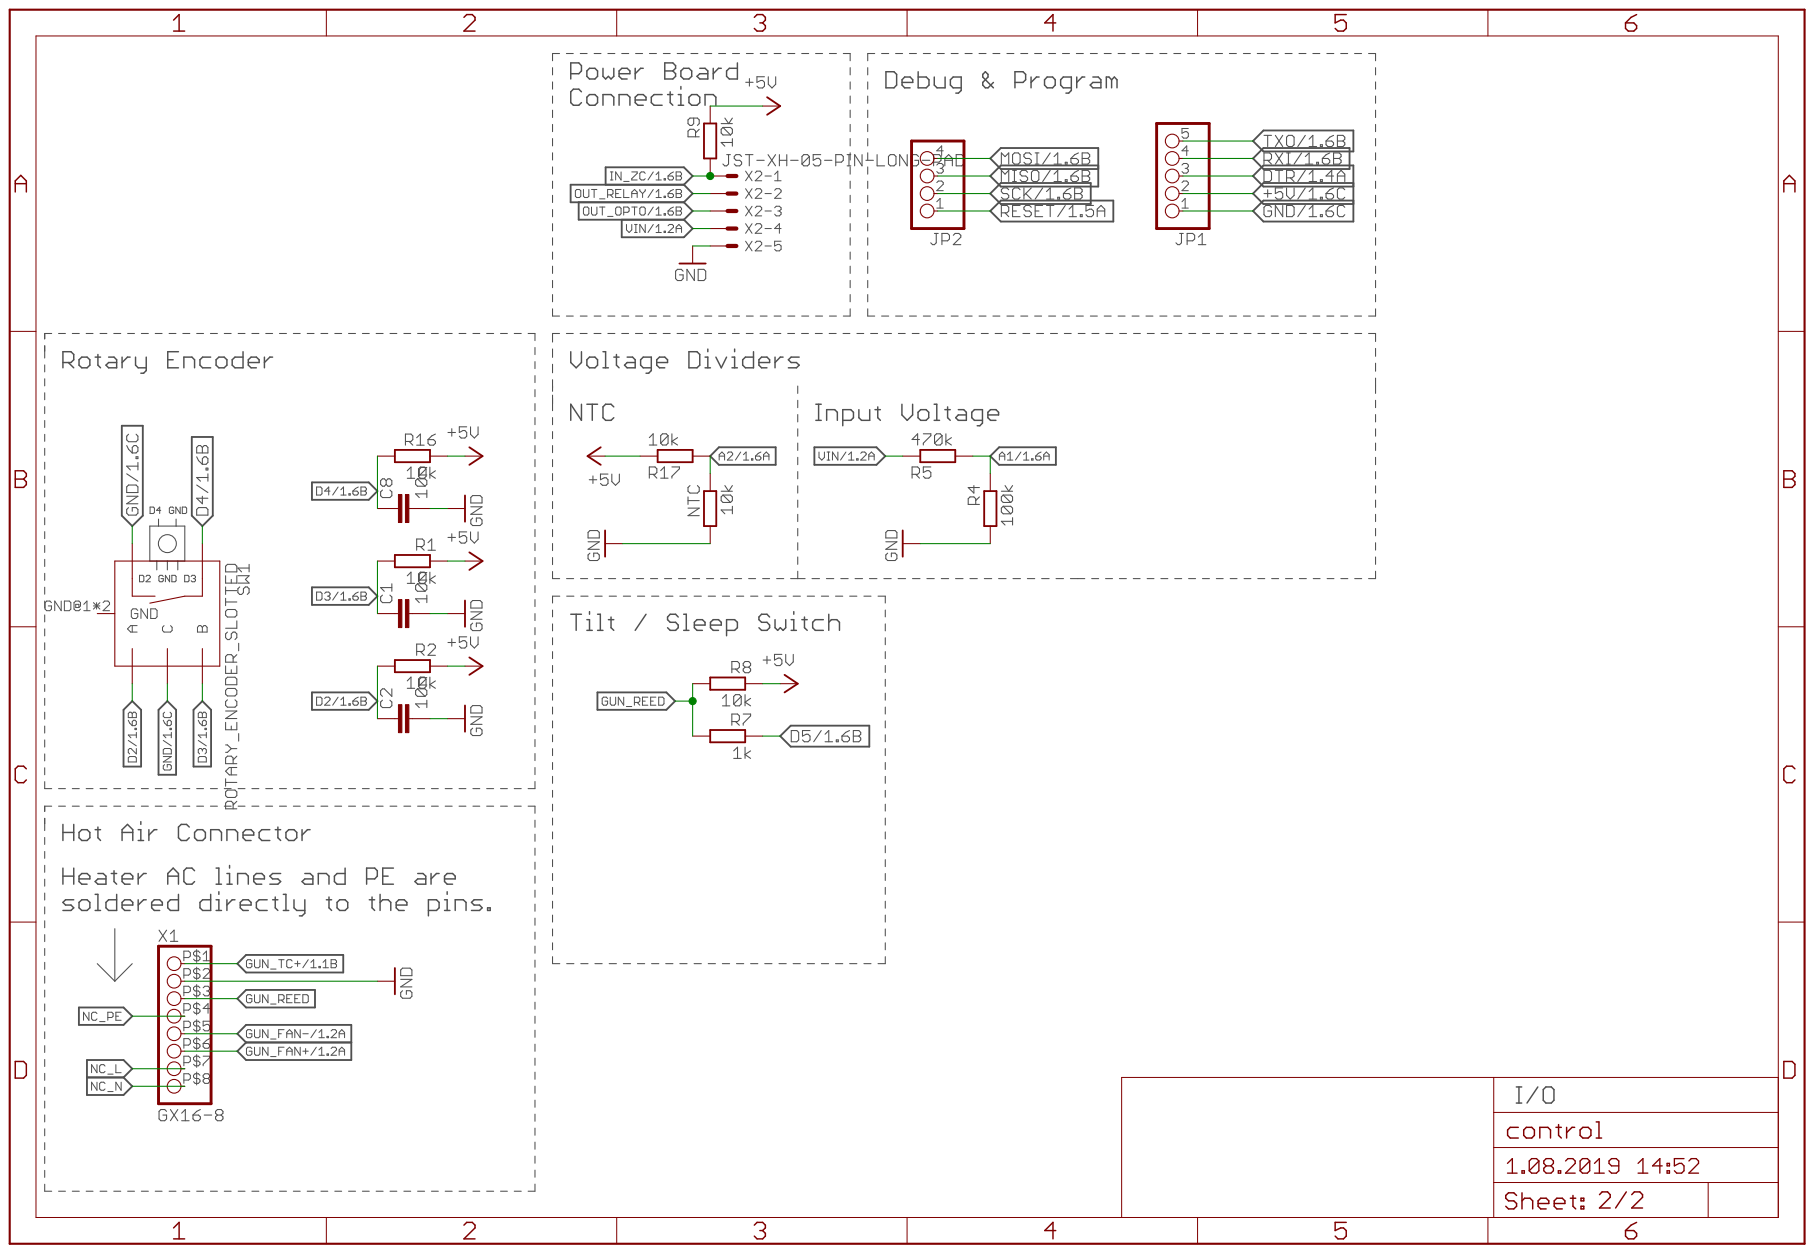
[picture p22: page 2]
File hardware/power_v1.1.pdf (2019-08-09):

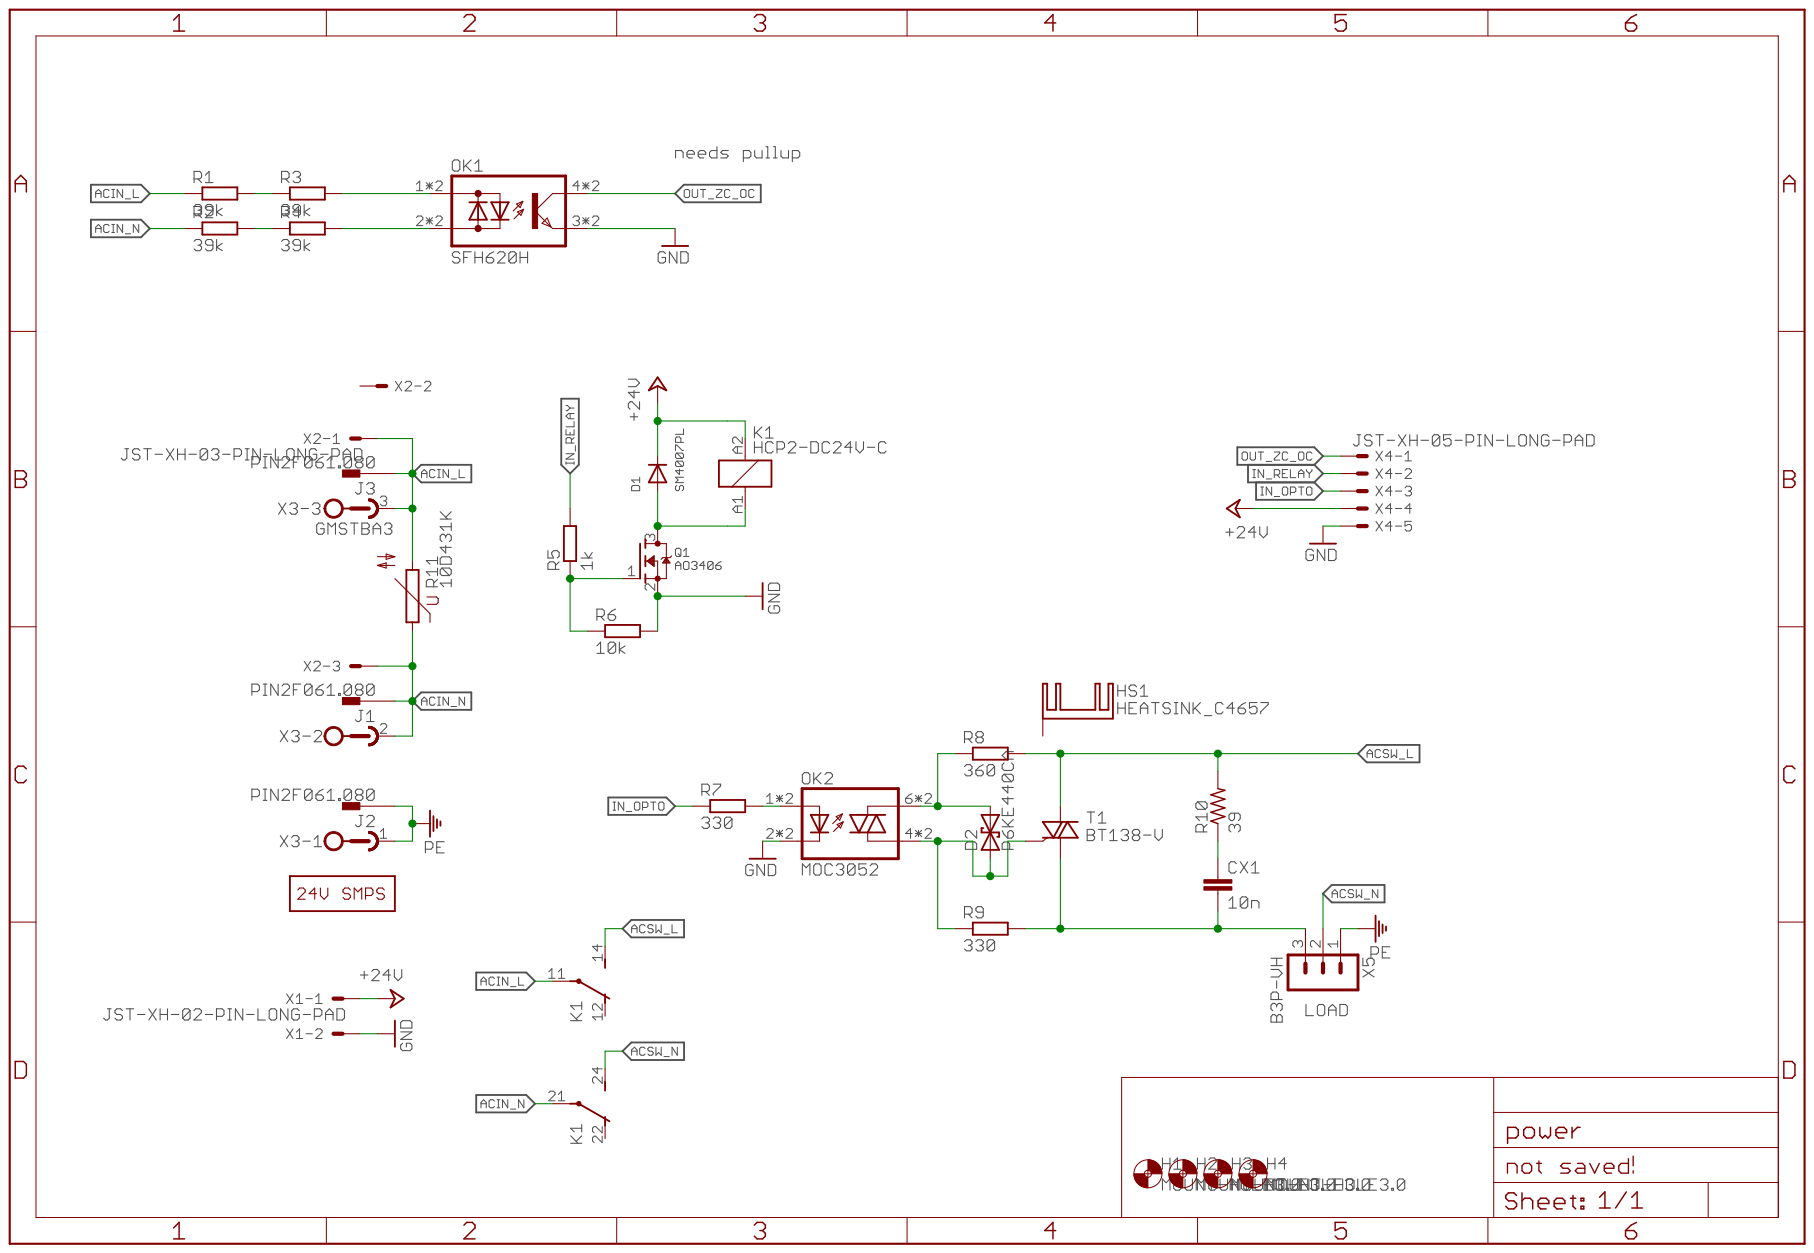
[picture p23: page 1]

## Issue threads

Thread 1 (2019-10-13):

When will you open the source code?

GioLangLe, 2019-10-13:
Hello,I think this is a great project, I think I want to build it.
- I have a recently damaged hot air station.
I don't know when you open up its source code.
- Can I build it on Arduino Nano? Thank you
